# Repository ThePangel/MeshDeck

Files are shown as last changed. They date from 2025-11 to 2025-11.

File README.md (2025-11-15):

# MeshDeck

Standalone ESP32-S3 powered Meshtastic device!

---

Meshdeck is a Standalone Meshtastic device powered by an ESP32-S3, It has a built in keyboard and a touchscreen allowing you to communicate off grid without any phone, completely standalone.

I made this because I wanted to get into Meshtastic, and RF radio stuff, and the best way of learning is making

The keyboard is just a button matrix connected to an RP2040 which will act as an i2c slave and send keycodes to the esp. 

---

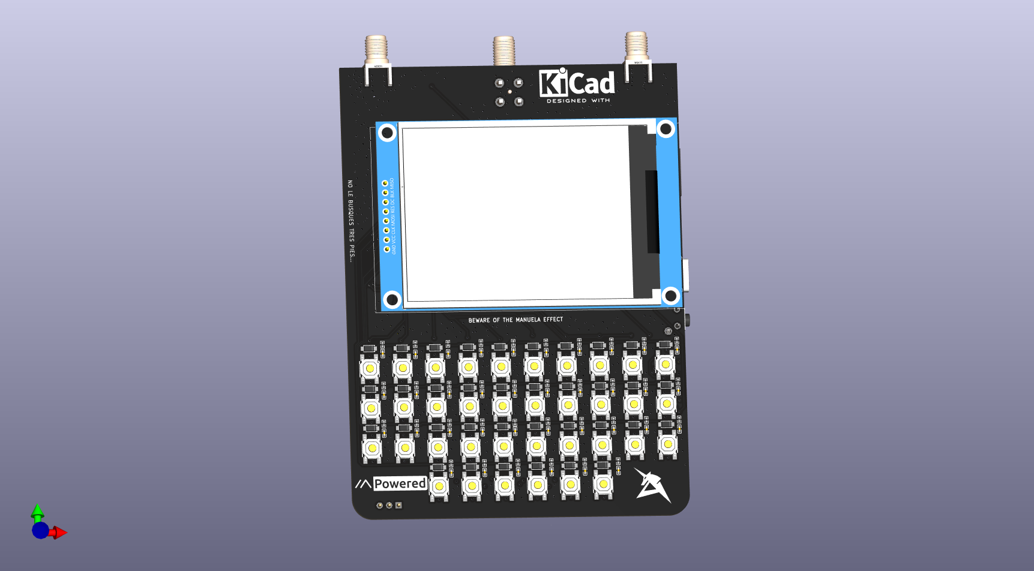
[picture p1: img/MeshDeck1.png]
  
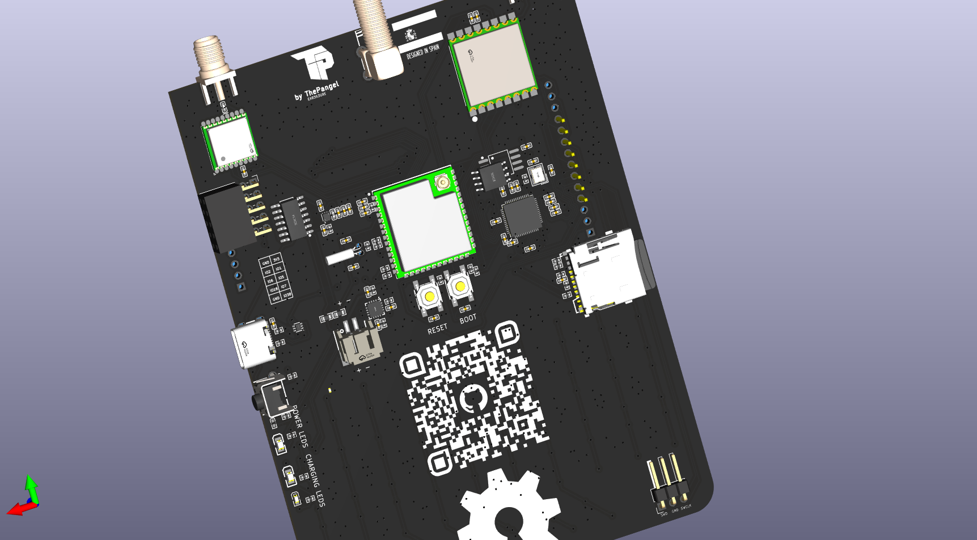
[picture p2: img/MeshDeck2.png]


---

## Bill of Materials (BOM)

| Designator | Footprint | Quantity | Value | LCSC Part # |
|---|---|---|---|---|
| C1 | C0402 | 1 | 22uF | C105226 |
| C10, C11, C12, C19 | C0402 | 4 | 10uF | C15525 |
| C13, C2, C20, C22, C23, C24, C25, C26, C27, C28, C30, C31, C32, C35, C36, C37, C38, C39, C4, C40, C41, C42, C43, C44, C45, C46, C47, C48, C49, C5, C50, C51, C52, C53, C54, C55, C56, C57, C58, C59, C60, C61, C62, C63, C64, C65, C66, C67, C68, C69, C70 | C0402 | 51 | 0.1uF | C1525 |
| C14, C15 | C0402 | 2 | 12pF | C1547 |
| C16, C18, C21, C29, C3, C7 | C0402 | 6 | 1uF | C14445 |
| C17 | C0402 | 1 | 1Nf | C1523 |
| C33, C34 | C0402 | 2 | 15pF | C1548 |
| C6, C8, C9 | C0402 | 3 | 4.7 uF | C23733 |
| CARD1 | TF-SMD_503398-1892 | 1 | 503398-1892 | C428492 |
| CN1 | COMM-SMD_18P-L10.1-W9.7-P1.1-TL_L76-LB  | 1 | ATGM336H-6N-74  | C5804601 |
| D1 | SOT-666-6_L1.6-W1.2-P0.50-LS1.6-BR | 1 | USBLC6-2P6 | C15999 |
| D10-D37 | SOD-123_L2.8-W1.8-LS3.7-RD | 36 | 1N4148W T4 | C2099 |
| H1 | CONN-SMD_2P-P2.00_XUNPU_WAFER-PH2.0-2PWB| 1 | WAFER-PH2.0-2PWB| C3029440 |
| J1 | PinHeader_1x03_P2.54mm_Horizontal | 1 | Conn_01x03_MountingPin | - |
| J2 | PinSocket_2x05_P2.54mm_Horizontal | 1 | Conn_02x05_Odd_Even | - |
| L1 | L0402 | 1 | 0.47 µH | C5788770 |
| L2 | L0402-RD | 1 | 47nH | C471397 |
| LED1, LED3 | LED0805-R-RD | 2 | 0805G (Green) | C2297 |
| LED2 | LED0603-RD | 1 | Blue light 0603 | C2288 |
| LED4 | LED0402-RD | 1 | red | C130719 |
| R1, R13, R17-R25 | R0402 | 9 | 10KOhm | C25531 |
| R10, R9 | R0402 | 2 | 1.8k | C25871 |
| R11, R16 | R0402 | 2 | 10K | C25744 |
| R12, R14, R15, R2-R4 | R0402 | 6 | 0 Ohm | C17168 |
| R19, R20 | R0402 | 2 | 220ohm | C25091 |
| R26-R64 | R0402 | 37 | 1k | C11702 |
| R5, R6 | R0402 | 2 | 5.1k | C25905 |
| R62, R63 | R0603 | 2 | 100k | C14675 |
| R7 | R0402 | 1 | 1.5K | C25867 |
| R8 | R0402 | 1 | 1.5K | C25867 |
| RF1, RF2 | SMA-SMD_HJ-SMA023 | 2 | HJ-SMA023 | C1509219 |
| SW1-SW39 | SW-SMD_4P-L5.2-W5.2-P3.70-LS6.5 | 38 | 4*4*1.7 | C10852 |
| SW3 | KEY-TH_4P-L7.5-W6.8-P4.50-LS7.2 | 1 | SKHHLVA010 | C110289 |
| U1 | WIRELM-SMD_ESP32-S3-WROOM-1U | 1 | ESP32-S3-WROOM-1U-N16R8 | C3013946 |
| U10 | CRYSTAL-SMD_4P-L3.2-W2.5-BL | 1 | ABM8-272-T3_C20625731 | C20625731 |
| U2 | WIRELM-SMD_SX1278S165SY-T-X1 | 1 | SX1262S8S+T-X1  | C718838 |
| U3 | VSON-6_L1.5-W1.5-P0.50-TL | 1 | TPS6282533DMQR  | C3189971 |
| U4 | QFN-16_L3.0-W3.0-P0.50-TL-EP1.7 | 1 | BQ24074RGTR | C54313 |
| U5 | OSC-TH_BD2.0-P0.50 | 1 | RN32768114 | C7206316 |
| U6 | 2.8 SPI LCD TFT ST7789 | 1 | ~ | - |
| U7 | SOIC-14_L8.7-W3.9-P1.27-LS6.0-BL | 1 | CD4013BM | C347580 |
| U8 | LQFN-56_L7.0-W7.0-P0.4-EP | 1 | RP2040 | C2040 |
| U9 | SOIC-8_L5.3-W5.3-P1.27-LS8.0-BL | 1 | W25Q128JVSIQTR  | C97521 |
| USBC1 | USB-C_SMD-TYPE-C-31-M-12_1 | 1 | TYPE-C-31-M-12  | C165948 |

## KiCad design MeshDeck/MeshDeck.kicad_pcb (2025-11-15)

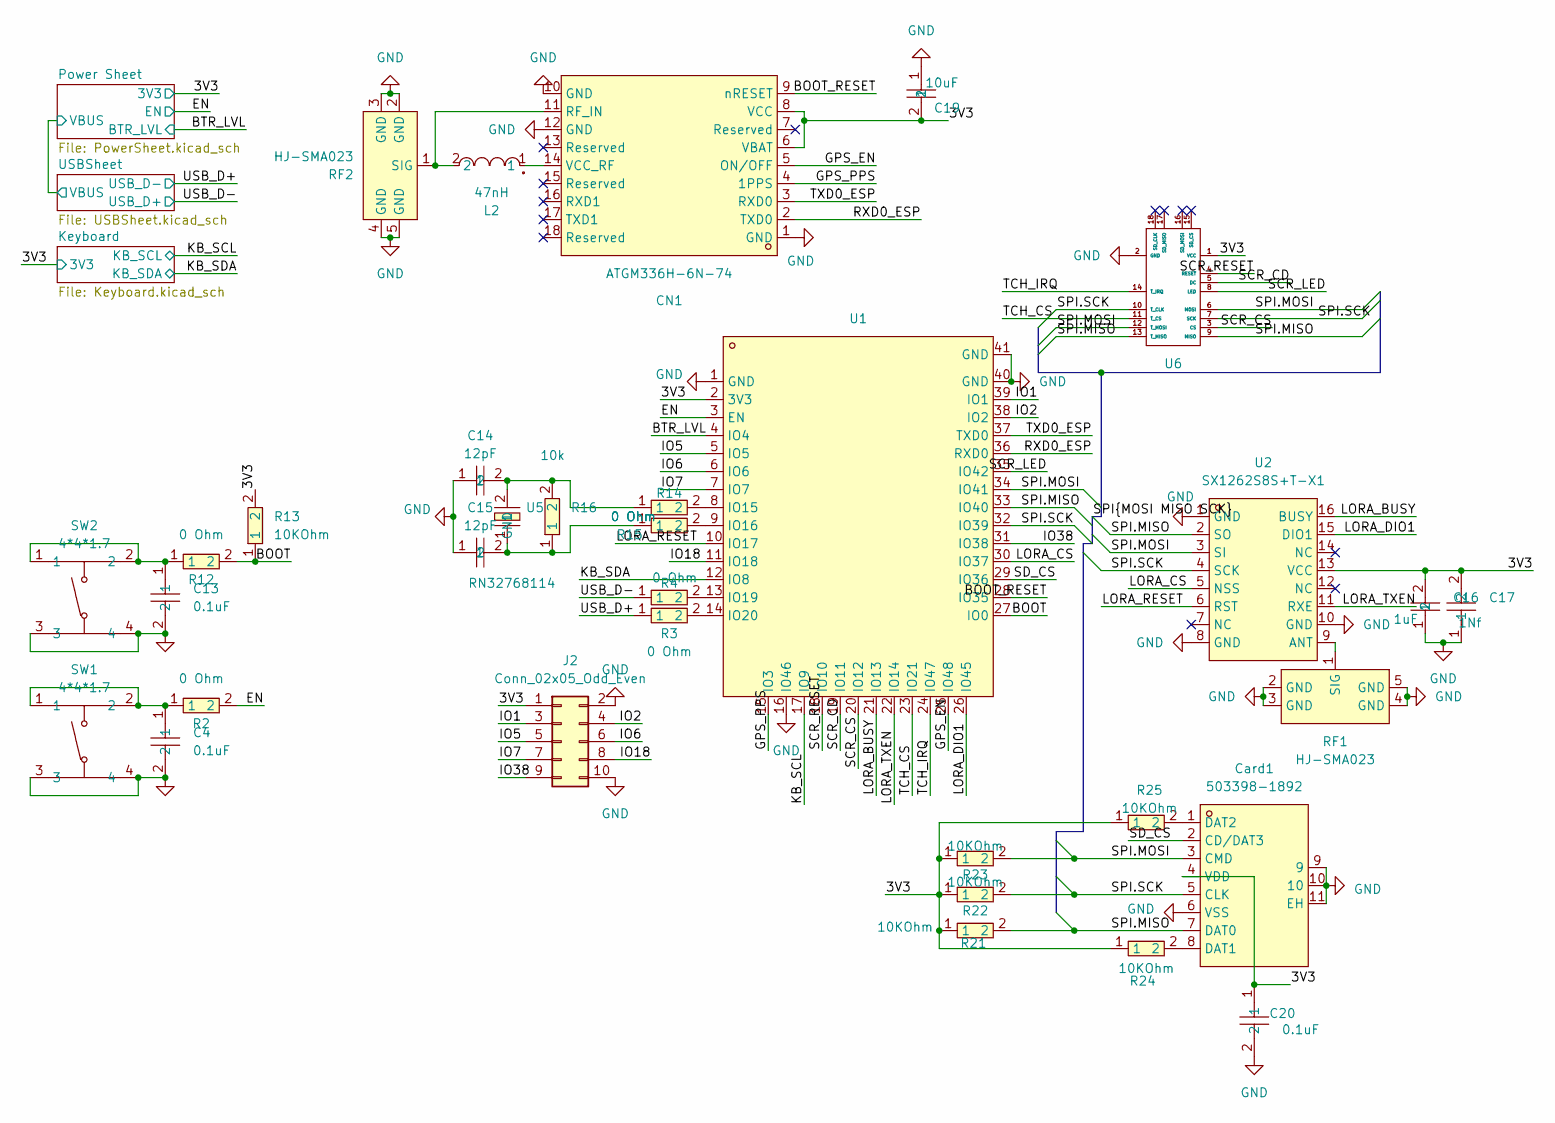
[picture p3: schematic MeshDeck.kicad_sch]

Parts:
C4, C13, C20: 0.1uF; C0402; LCSC Part C1525
C14, C15: 12pF; C0402; LCSC Part C1547
C16: 1uF; C0402; LCSC Part C14445
C17: 1Nf; C0402; LCSC Part C1523
C19: 10uF; C0402; LCSC Part C15525
CN1: ATGM336H-6N-74; COMM-SMD_18P-L10.1-W9.7-P1.1-TL_L76-LB; LCSC Part C5804601
Card1: 503398-1892; TF-SMD_503398-1892; LCSC Part C428492
J2: Conn_02x05_Odd_Even; PinSocket_2x05_P2.54mm_Horizontal
L2: 47nH; L0402-RD; LCSC Part C471397
R2, R3, R4, R12, R14, R15: 0 Ohm; R0402; LCSC Part C17168
R13, R21, R22, R23, R24, R25: 10KOhm; R0402; LCSC Part C25531
R16: 10k; R0402; LCSC Part C25744
RF1, RF2: HJ-SMA023; SMA-SMD_HJ-SMA023; LCSC Part C1509219
SW1, SW2: 4*4*1.7; SW-SMD_4P-L5.2-W5.2-P3.70-LS6.5; LCSC Part C10852
U1: ESP32-S3-WROOM-1U-N16R8; WIRELM-SMD_ESP32-S3-WROOM-1U; LCSC Part C3013946
U2: SX1262S8S+T-X1; WIRELM-SMD_SX1278S165SY-T-X1; LCSC Part C718838
U5: RN32768114; OSC-TH_BD2.0-P0.50; LCSC Part C7206316
U6: 2.8 SPI LCD TFT ST7789

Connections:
/3V3: C16.2, C17.2, C19.2, C20.1, CN1.6 (VBAT), CN1.8 (VCC), Card1.4 (VDD), J2.1, R13.2, R21.1, R22.1, R23.1, R24.1, R25.1, U1.2 (3V3), U2.13 (VCC), U6.1 (VCC); also elsewhere on the board
/BOOT: R12.2, R13.1, U1.27 (IO0)
/BOOT_RESET: CN1.9 (nRESET), U1.28 (IO35)
/BTR_LVL: U1.4 (IO4); also elsewhere on the board
/EN: R2.2, U1.3 (EN); also elsewhere on the board
/GPS_EN: CN1.5 (ON/OFF), U1.25 (IO48)
/GPS_PPS: CN1.4 (1PPS), U1.15 (IO3)
/IO1: J2.3, U1.39 (IO1)
/IO2: J2.4, U1.38 (IO2)
/IO5: J2.5, U1.5 (IO5)
/IO6: J2.6, U1.6 (IO6)
/IO7: J2.7, U1.7 (IO7)
/IO18: J2.8, U1.11 (IO18)
/IO38: J2.9, U1.31 (IO38)
/KB_SCL: U1.17 (IO9); also elsewhere on the board
/KB_SDA: U1.12 (IO8); also elsewhere on the board
/LORA_BUSY: U1.21 (IO13), U2.16 (BUSY)
/LORA_CS: U1.30 (IO37), U2.5 (NSS)
/LORA_DIO1: U1.26 (IO45), U2.15 (DIO1)
/LORA_RESET: U1.10 (IO17), U2.6 (RST)
/LORA_TXEN: U1.22 (IO14), U2.11 (RXE)
/RXD0_ESP: CN1.2 (TXD0), U1.36 (RXD0)
/SCR_CD: U1.19 (IO11), U6.5 (DC)
/SCR_CS: U1.20 (IO12), U6.3 (CS)
/SCR_LED: U1.35 (IO42), U6.8 (LED)
/SCR_RESET: U1.18 (IO10), U6.4 (RESET)
/SD_CS: Card1.2 (CD/DAT3), U1.29 (IO36)
/SPI.MISO: Card1.7 (DAT0), R21.2, U1.33 (IO40), U2.2 (SO), U6.9 (MISO), U6.13 (T_MISO)
/SPI.MOSI: Card1.3 (CMD), R23.2, U1.34 (IO41), U2.3 (SI), U6.6 (MOSI), U6.12 (T_MOSI)
/SPI.SCK: Card1.5 (CLK), R22.2, U1.32 (IO39), U2.4 (SCK), U6.7 (SCK), U6.10 (T_CLK)
/TCH_CS: U1.23 (IO21), U6.11 (T_CS)
/TCH_IRQ: U1.24 (IO47), U6.14 (T_IRQ)
/TXD0_ESP: CN1.3 (RXD0), U1.37 (TXD0)
/USB_D+: R3.1; also elsewhere on the board
/USB_D-: R4.1; also elsewhere on the board
GND: C4.2, C13.2, C14.1, C15.1, C16.1, C17.1, C19.1, C20.2, CN1.1 (GND), CN1.10 (GND), CN1.12 (GND), Card1.6 (VSS), Card1.9, Card1.10, Card1.11 (EH), J2.2, J2.10, RF1.2 (GND), RF1.3 (GND), RF1.4 (GND), RF1.5 (GND), RF2.2 (GND), RF2.3 (GND), RF2.4 (GND), RF2.5 (GND), SW1.3, SW1.4, SW2.3, SW2.4, U1.1 (GND), U1.16 (IO46), U1.40 (GND), U1.41 (GND), U2.1 (GND), U2.8 (GND), U2.10 (GND), U6.2 (GND); also elsewhere on the board
unnamed: C4.1, R2.1, SW1.1, SW1.2
unnamed: C13.1, R12.1, SW2.1, SW2.2
unnamed: C15.2, R15.1, R16.1, U5.1
unnamed: CN1.11 (RF_IN), L2.2, RF2.1 (SIG)
unnamed: CN1.14 (VCC_RF), L2.1
unnamed: Card1.8 (DAT1), R24.2
unnamed: Card1.1 (DAT2), R25.2
unnamed: RF1.1 (SIG), U2.9 (ANT)
unnamed: R14.2, U1.8 (IO15)
unnamed: R15.2, U1.9 (IO16)
unnamed: R4.2, U1.13 (IO19)
unnamed: R3.2, U1.14 (IO20)
unnamed: C14.2, R14.1, R16.2, U5.2 (GND)

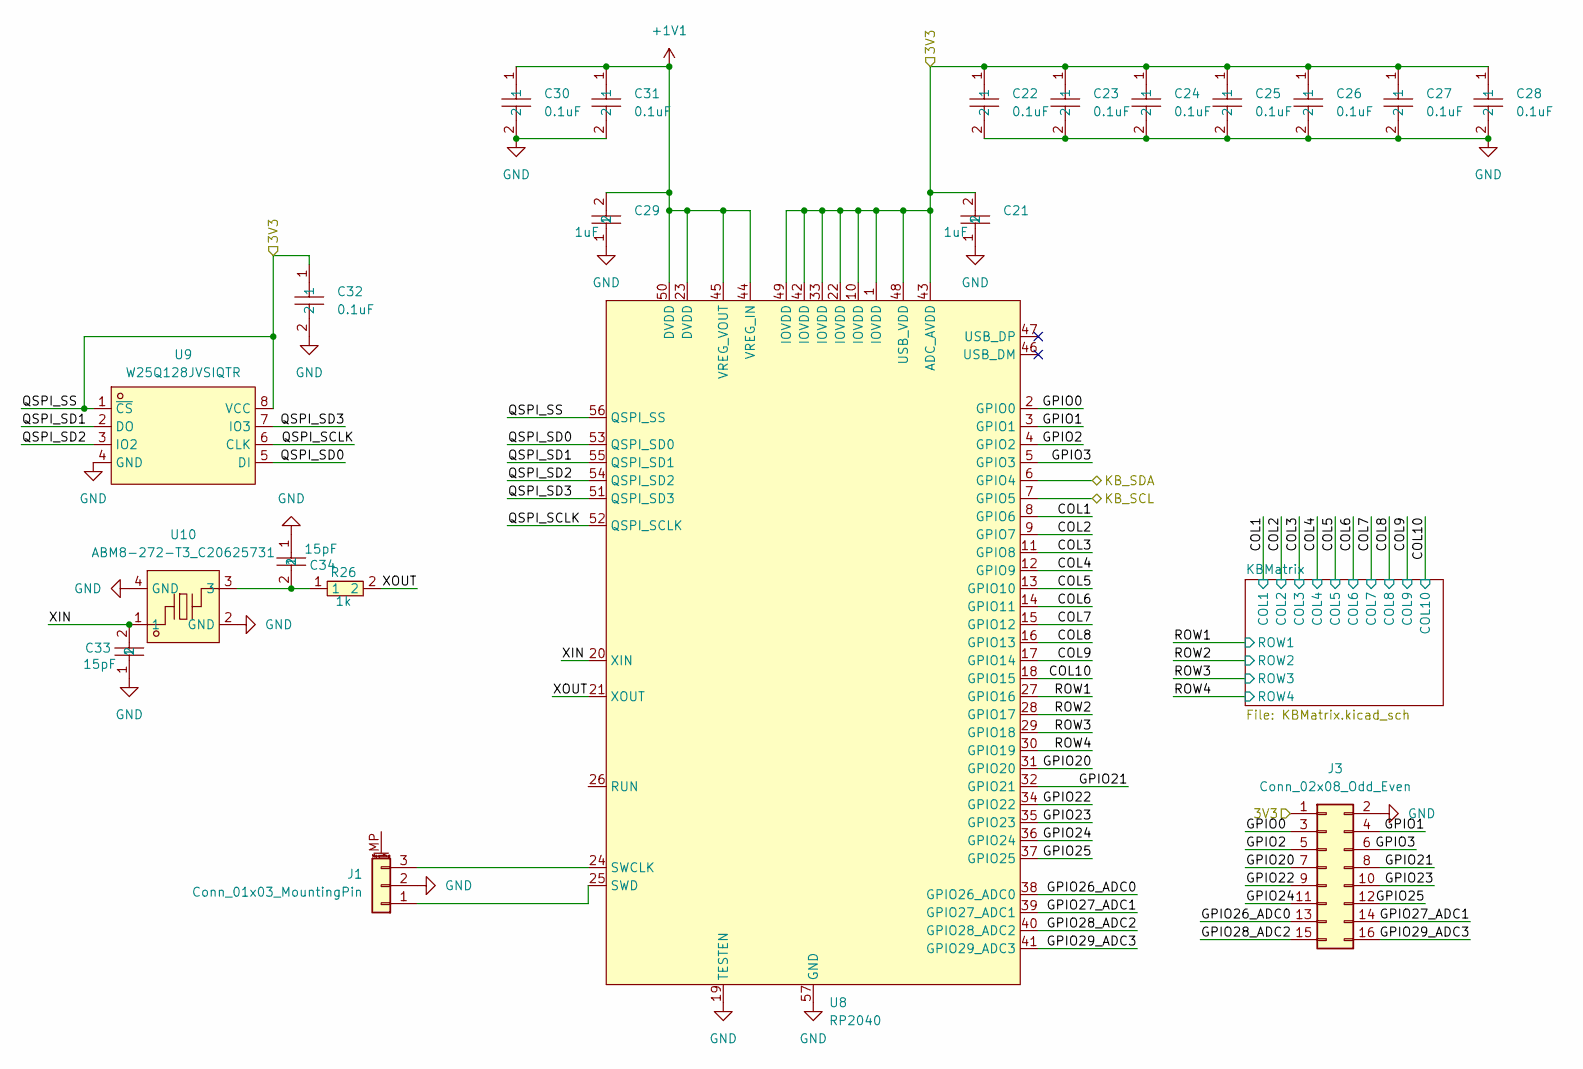
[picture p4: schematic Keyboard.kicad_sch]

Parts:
C21, C29: 1uF; C0402; LCSC Part C14445
C22, C23, C24, C25, C26, C27, C28, C30, C31, C32: 0.1uF; C0402; LCSC Part C1525
C33, C34: 15pF; C0402; LCSC Part C1548
J1: Conn_01x03_MountingPin; PinHeader_1x03_P2.54mm_Horizontal
J3: Conn_02x08_Odd_Even; PinSocket_2x08_P2.54mm_Horizontal
R26: 1k; R0402; LCSC Part C11702
U8: RP2040; LQFN-56_L7.0-W7.0-P0.4-EP; LCSC Part C2040
U9: W25Q128JVSIQTR; SOIC-8_L5.3-W5.3-P1.27-LS8.0-BL; LCSC Part C97521
U10: ABM8-272-T3_C20625731; CRYSTAL-SMD_4P-L3.2-W2.5-BL; LCSC Part C20625731

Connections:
+1V1: C29.2, C30.1, C31.1, U8.23 (DVDD), U8.44 (VREG_IN), U8.45 (VREG_VOUT), U8.50 (DVDD)
/3V3: C21.2, C22.1, C23.1, C24.1, C25.1, C26.1, C27.1, C28.1, C32.1, J3.1, U8.1 (IOVDD), U8.10 (IOVDD), U8.22 (IOVDD), U8.33 (IOVDD), U8.42 (IOVDD), U8.43 (ADC_AVDD), U8.48 (USB_VDD), U8.49 (IOVDD), U8.56 (QSPI_SS), U9.1 (~CS), U9.8 (VCC); also elsewhere on the board
/KB_SCL: U8.7 (GPIO5); also elsewhere on the board
/KB_SDA: U8.6 (GPIO4); also elsewhere on the board
/Keyboard/COL1: U8.8 (GPIO6); also elsewhere on the board
/Keyboard/COL2: U8.9 (GPIO7); also elsewhere on the board
/Keyboard/COL3: U8.11 (GPIO8); also elsewhere on the board
/Keyboard/COL4: U8.12 (GPIO9); also elsewhere on the board
/Keyboard/COL5: U8.13 (GPIO10); also elsewhere on the board
/Keyboard/COL6: U8.14 (GPIO11); also elsewhere on the board
/Keyboard/COL7: U8.15 (GPIO12); also elsewhere on the board
/Keyboard/COL8: U8.16 (GPIO13); also elsewhere on the board
/Keyboard/COL9: U8.17 (GPIO14); also elsewhere on the board
/Keyboard/COL10: U8.18 (GPIO15); also elsewhere on the board
/Keyboard/GPIO0: J3.3, U8.2 (GPIO0)
/Keyboard/GPIO1: J3.4, U8.3 (GPIO1)
/Keyboard/GPIO2: J3.5, U8.4 (GPIO2)
/Keyboard/GPIO3: J3.6, U8.5 (GPIO3)
/Keyboard/GPIO20: J3.7, U8.31 (GPIO20)
/Keyboard/GPIO21: J3.8, U8.32 (GPIO21)
/Keyboard/GPIO22: J3.9, U8.34 (GPIO22)
/Keyboard/GPIO23: J3.10, U8.35 (GPIO23)
/Keyboard/GPIO24: J3.11, U8.36 (GPIO24)
/Keyboard/GPIO25: J3.12, U8.37 (GPIO25)
/Keyboard/GPIO26_ADC0: J3.13, U8.38 (GPIO26_ADC0)
/Keyboard/GPIO27_ADC1: J3.14, U8.39 (GPIO27_ADC1)
/Keyboard/GPIO28_ADC2: J3.15, U8.40 (GPIO28_ADC2)
/Keyboard/GPIO29_ADC3: J3.16, U8.41 (GPIO29_ADC3)
/Keyboard/QSPI_SCLK: U8.52 (QSPI_SCLK), U9.6 (CLK)
/Keyboard/QSPI_SD0: U8.53 (QSPI_SD0), U9.5 (DI)
/Keyboard/QSPI_SD1: U8.55 (QSPI_SD1), U9.2 (DO)
/Keyboard/QSPI_SD2: U8.54 (QSPI_SD2), U9.3 (IO2)
/Keyboard/QSPI_SD3: U8.51 (QSPI_SD3), U9.7 (IO3)
/Keyboard/ROW1: U8.27 (GPIO16); also elsewhere on the board
/Keyboard/ROW2: U8.28 (GPIO17); also elsewhere on the board
/Keyboard/ROW3: U8.29 (GPIO18); also elsewhere on the board
/Keyboard/ROW4: U8.30 (GPIO19); also elsewhere on the board
/Keyboard/XIN: C33.2, U8.20 (XIN), U10.1
/Keyboard/XOUT: R26.2, U8.21 (XOUT)
GND: C21.1, C22.2, C23.2, C24.2, C25.2, C26.2, C27.2, C28.2, C29.1, C30.2, C31.2, C32.2, C33.1, C34.1, J1.2, J3.2, U8.19 (TESTEN), U8.57 (GND), U9.4 (GND), U10.2 (GND), U10.4 (GND); also elsewhere on the board
unnamed: C34.2, R26.1, U10.3
unnamed: J1.1, U8.25 (SWD)
unnamed: J1.3, U8.24 (SWCLK)

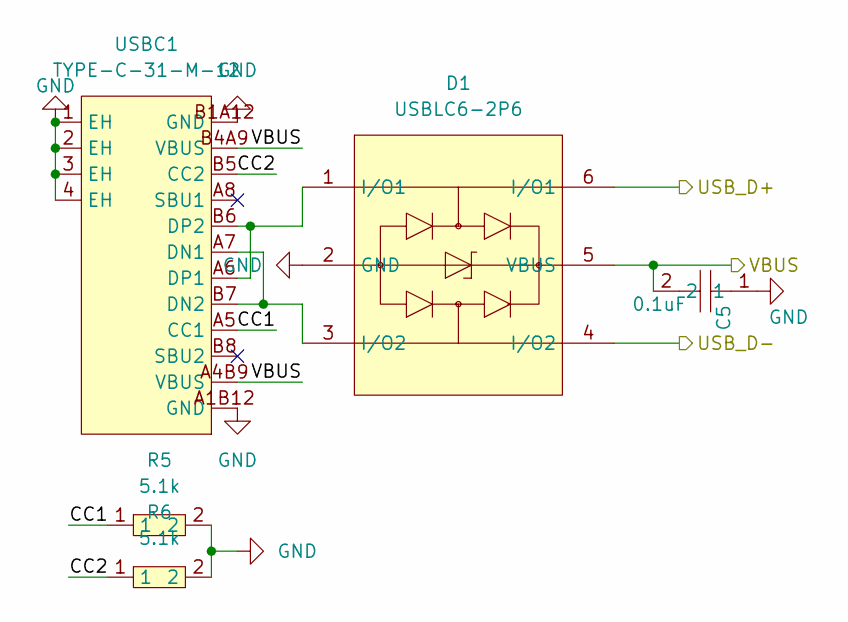
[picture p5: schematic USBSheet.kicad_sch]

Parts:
C5: 0.1uF; C0402; LCSC Part C1525
D1: USBLC6-2P6; SOT-666-6_L1.6-W1.2-P0.50-LS1.6-BR; LCSC Part C15999
R5, R6: 5.1k; R0402; LCSC Part C25905
USBC1: TYPE-C-31-M-12; USB-C_SMD-TYPE-C-31-M-12_1; LCSC Part C165948

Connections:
/USBSheet/CC1: R5.1, USBC1.A5 (CC1)
/USBSheet/CC2: R6.1, USBC1.B5 (CC2)
/USBSheet/VBUS: C5.2, D1.5 (VBUS), USBC1.A4B9 (VBUS), USBC1.B4A9 (VBUS); also elsewhere on the board
/USB_D+: D1.4 (I/O2); also elsewhere on the board
/USB_D-: D1.6 (I/O1); also elsewhere on the board
GND: C5.1, D1.2 (GND), R5.2, R6.2, USBC1.1 (EH), USBC1.2 (EH), USBC1.3 (EH), USBC1.4 (EH), USBC1.A1B12 (GND), USBC1.B1A12 (GND); also elsewhere on the board
unnamed: D1.3 (I/O2), USBC1.A7 (DN1), USBC1.B7 (DN2)
unnamed: D1.1 (I/O1), USBC1.A6 (DP1), USBC1.B6 (DP2)

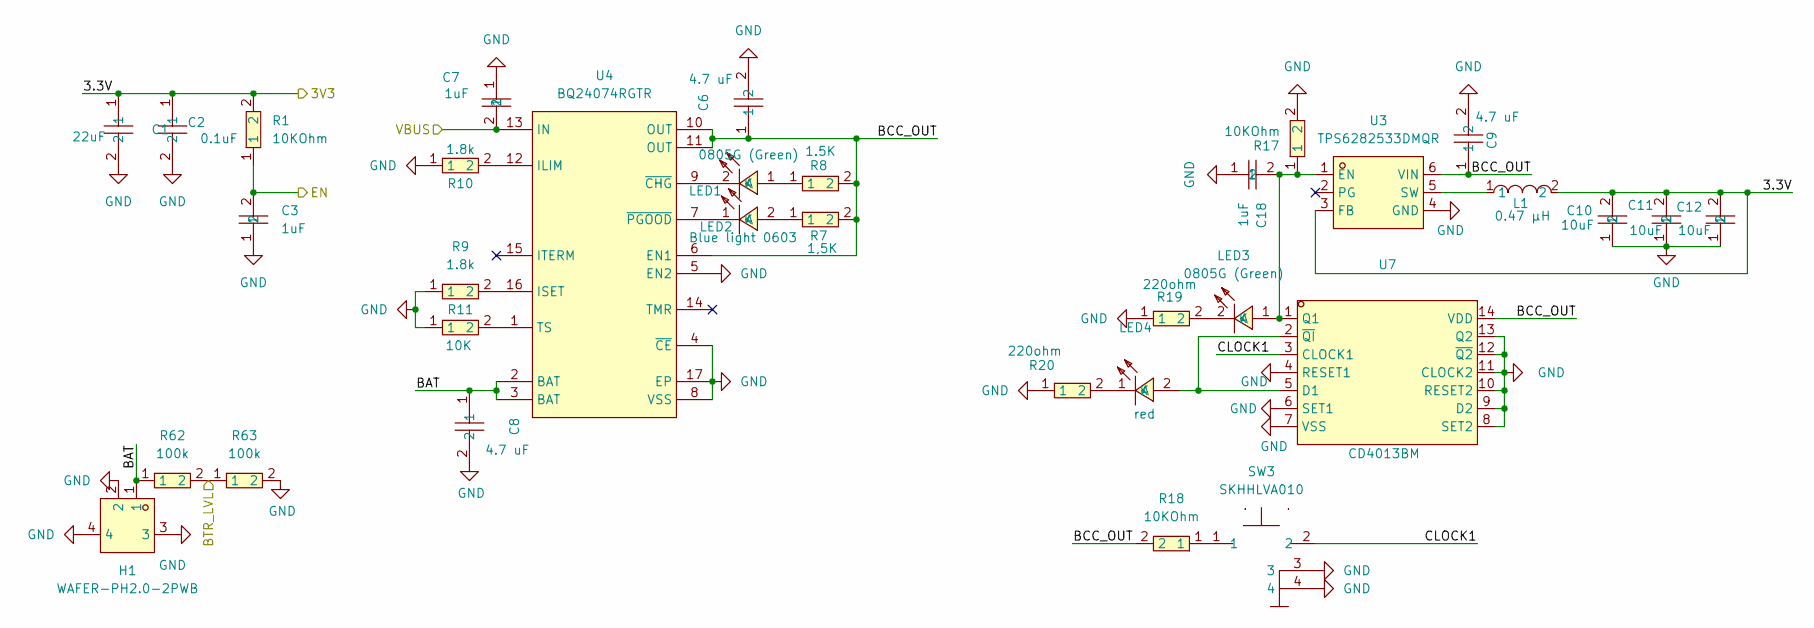
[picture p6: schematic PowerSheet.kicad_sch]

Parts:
C1: 22uF; C0402; LCSC Part C105226
C2: 0.1uF; C0402; LCSC Part C1525
C3, C7, C18: 1uF; C0402; LCSC Part C14445
C6, C8, C9: 4.7 uF; C0402; LCSC Part C23733
C10, C11, C12: 10uF; C0402; LCSC Part C15525
H1: WAFER-PH2.0-2PWB; CONN-SMD_2P-P2.00_XUNPU_WAFER-PH2.0-2PWB; LCSC Part C3029440
L1: 0.47 µH; L0402; LCSC Part C5788770
LED1, LED3: 0805G (Green); LED0805-R-RD; LCSC Part C2297
LED2: Blue light 0603; LED0603-RD; LCSC Part C2288
LED4: red; LED0402-RD; LCSC Part C130719
R1, R17, R18: 10KOhm; R0402; LCSC Part C25531
R7: 1,5K; R0402; LCSC Part C25867
R8: 1.5K; R0402; LCSC Part C25867
R9, R10: 1.8k; R0402; LCSC Part C25871
R11: 10K; R0402; LCSC Part C25744
R19, R20: 220ohm; R0402; LCSC Part C25091
R62, R63: 100k; R0603; LCSC Part C14675
SW3: SKHHLVA010; KEY-TH_4P-L7.5-W6.8-P4.50-LS7.2; LCSC Part C110289
U3: TPS6282533DMQR; VSON-6_L1.5-W1.5-P0.50-TL; LCSC Part C3189971
U4: BQ24074RGTR; QFN-16_L3.0-W3.0-P0.50-TL-EP1.7; LCSC Part C54313
U7: CD4013BM; SOIC-14_L8.7-W3.9-P1.27-LS6.0-BL; LCSC Part C347580

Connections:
/3V3: C1.1, C2.1, C10.2, C11.2, C12.2, L1.2, R1.2, U3.3 (FB); also elsewhere on the board
/BTR_LVL: R62.2, R63.1; also elsewhere on the board
/EN: C3.2, R1.1; also elsewhere on the board
/Power Sheet/BAT: C8.1, H1.1, R62.1, U4.2 (BAT), U4.3 (BAT)
/Power Sheet/BCC_OUT: C6.1, C9.1, R7.2, R8.2, R18.2, U3.6 (VIN), U4.6 (EN1), U4.10 (OUT), U4.11 (OUT), U7.14 (VDD)
/Power Sheet/CLOCK1: SW3.2, U7.3 (CLOCK1)
/USBSheet/VBUS: C7.2, U4.13 (IN); also elsewhere on the board
GND: C1.2, C2.2, C3.1, C6.2, C7.1, C8.2, C9.2, C10.1, C11.1, C12.1, C18.1, H1.2, H1.3, H1.4, R9.1, R10.1, R11.1, R17.2, R19.1, R20.1, R63.2, SW3.3, SW3.4, U3.4 (GND), U4.4 (~CE), U4.5 (EN2), U4.8 (VSS), U4.17 (EP), U7.4 (RESET1), U7.6 (SET1), U7.7 (VSS), U7.8 (SET2), U7.9 (D2), U7.10 (RESET2), U7.11 (CLOCK2), U7.12 (~Q2), U7.13 (Q2); also elsewhere on the board
unnamed: LED1.1 (A), R8.1
unnamed: LED1.2 (K), U4.9 (~CHG)
unnamed: LED2.2 (A), R7.1
unnamed: LED2.1 (K), U4.7 (~PGOOD)
unnamed: C18.2, LED3.1 (A), R17.1, U3.1 (EN), U7.1 (Q1)
unnamed: LED3.2 (K), R19.2
unnamed: LED4.2 (A), U7.2 (~QI), U7.5 (D1)
unnamed: LED4.1 (K), R20.2
unnamed: R18.1, SW3.1
unnamed: L1.1, U3.5 (SW)
unnamed: R10.2, U4.12 (ILIM)
unnamed: R9.2, U4.16 (ISET)
unnamed: R11.2, U4.1 (TS)

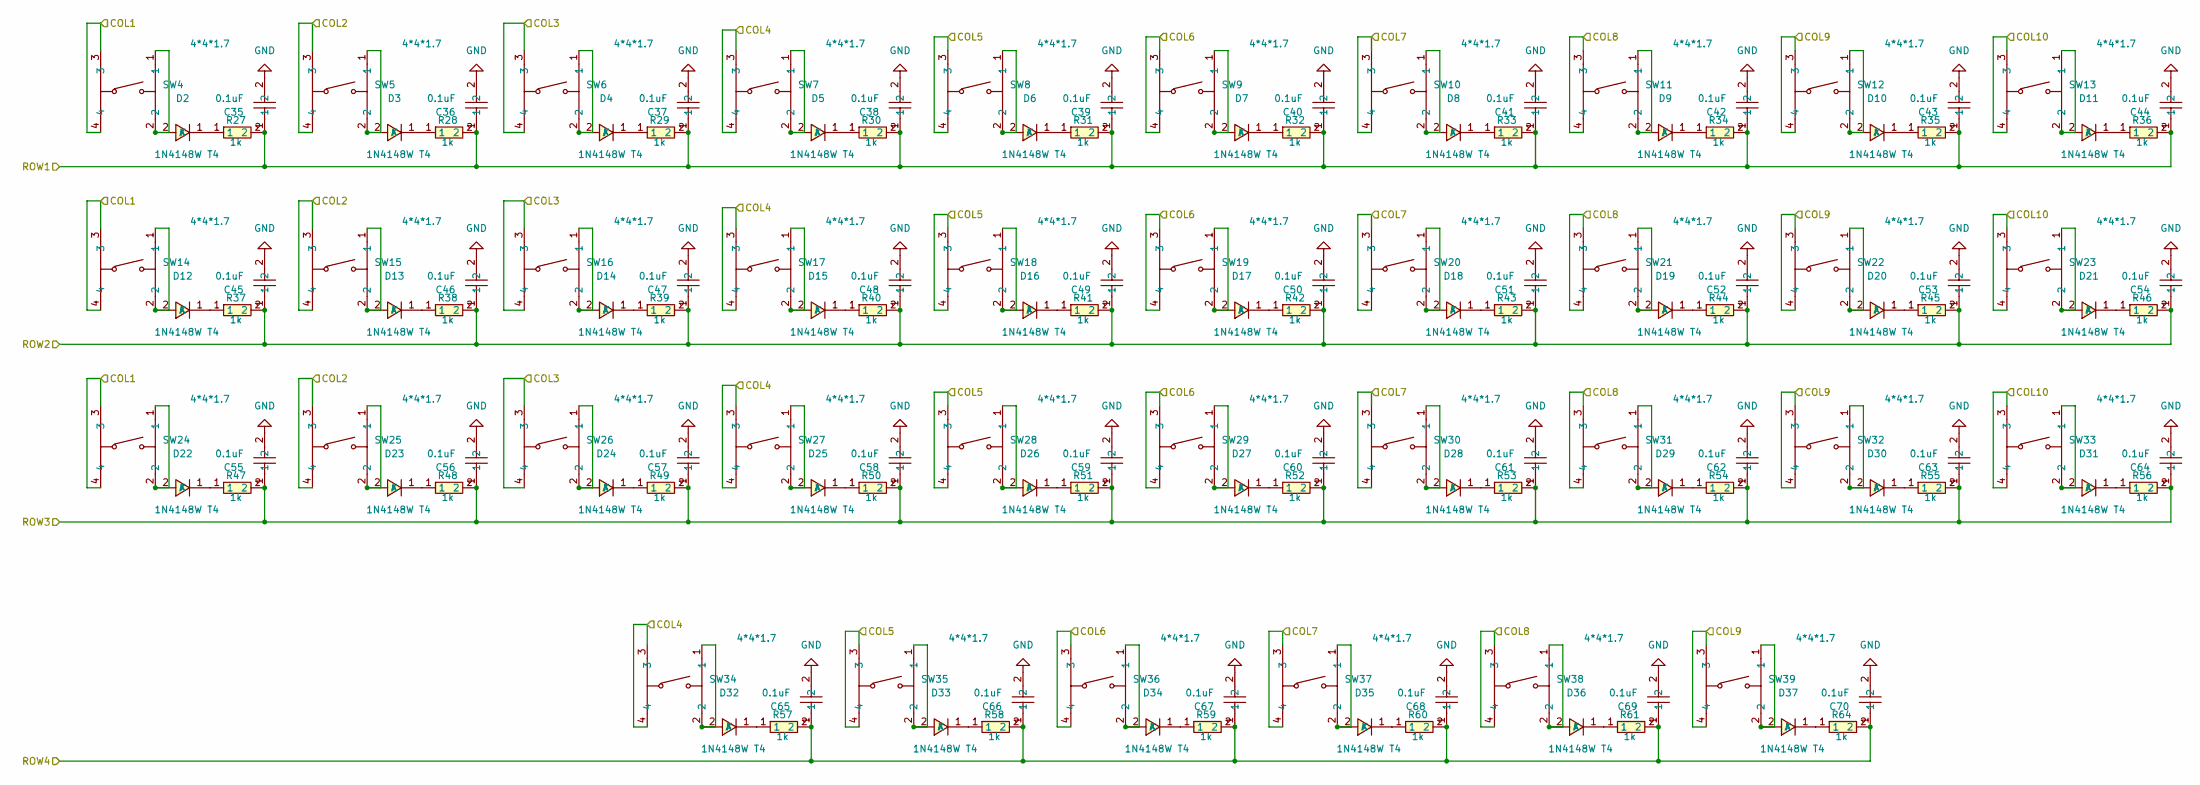
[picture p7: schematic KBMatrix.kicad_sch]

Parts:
C35, C36, C37, C38, C39, C40, C41, C42, C43, C44, C45, C46, C47, C48, C49, C50, C51, C52, C53, C54, C55, C56, C57, C58, C59, C60, C61, C62, C63, C64, C65, C66, C67, C68, C69, C70: 0.1uF; C0402; LCSC Part C1525
D2, D3, D4, D5, D6, D7, D8, D9, D10, D11, D12, D13, D14, D15, D16, D17, D18, D19, D20, D21, D22, D23, D24, D25, D26, D27, D28, D29, D30, D31, D32, D33, D34, D35, D36, D37: 1N4148W T4; SOD-123_L2.8-W1.8-LS3.7-RD; LCSC Part C2099
R27, R28, R29, R30, R31, R32, R33, R34, R35, R36, R37, R38, R39, R40, R41, R42, R43, R44, R45, R46, R47, R48, R49, R50, R51, R52, R53, R54, R55, R56, R57, R58, R59, R60, R61, R64: 1k; R0402; LCSC Part C11702
SW4, SW5, SW6, SW7, SW8, SW9, SW10, SW11, SW12, SW13, SW14, SW15, SW16, SW17, SW18, SW19, SW20, SW21, SW22, SW23, SW24, SW25, SW26, SW27, SW28, SW29, SW30, SW31, SW32, SW33, SW34, SW35, SW36, SW37, SW38, SW39: 4*4*1.7; SW-SMD_4P-L5.2-W5.2-P3.70-LS6.5; LCSC Part C10852

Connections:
/Keyboard/COL1: SW4.3, SW4.4, SW14.3, SW14.4, SW24.3, SW24.4; also elsewhere on the board
/Keyboard/COL2: SW5.3, SW5.4, SW15.3, SW15.4, SW25.3, SW25.4; also elsewhere on the board
/Keyboard/COL3: SW6.3, SW6.4, SW16.3, SW16.4, SW26.3, SW26.4; also elsewhere on the board
/Keyboard/COL4: SW7.3, SW7.4, SW17.3, SW17.4, SW27.3, SW27.4, SW34.3, SW34.4; also elsewhere on the board
/Keyboard/COL5: SW8.3, SW8.4, SW18.3, SW18.4, SW28.3, SW28.4, SW35.3, SW35.4; also elsewhere on the board
/Keyboard/COL6: SW9.3, SW9.4, SW19.3, SW19.4, SW29.3, SW29.4, SW36.3, SW36.4; also elsewhere on the board
/Keyboard/COL7: SW10.3, SW10.4, SW20.3, SW20.4, SW30.3, SW30.4, SW37.3, SW37.4; also elsewhere on the board
/Keyboard/COL8: SW11.3, SW11.4, SW21.3, SW21.4, SW31.3, SW31.4, SW38.3, SW38.4; also elsewhere on the board
/Keyboard/COL9: SW12.3, SW12.4, SW22.3, SW22.4, SW32.3, SW32.4, SW39.3, SW39.4; also elsewhere on the board
/Keyboard/COL10: SW13.3, SW13.4, SW23.3, SW23.4, SW33.3, SW33.4; also elsewhere on the board
/Keyboard/ROW1: C35.1, C36.1, C37.1, C38.1, C39.1, C40.1, C41.1, C42.1, C43.1, C44.1, R27.2, R28.2, R29.2, R30.2, R31.2, R32.2, R33.2, R34.2, R35.2, R36.2; also elsewhere on the board
/Keyboard/ROW2: C45.1, C46.1, C47.1, C48.1, C49.1, C50.1, C51.1, C52.1, C53.1, C54.1, R37.2, R38.2, R39.2, R40.2, R41.2, R42.2, R43.2, R44.2, R45.2, R46.2; also elsewhere on the board
/Keyboard/ROW3: C55.1, C56.1, C57.1, C58.1, C59.1, C60.1, C61.1, C62.1, C63.1, C64.1, R47.2, R48.2, R49.2, R50.2, R51.2, R52.2, R53.2, R54.2, R55.2, R56.2; also elsewhere on the board
/Keyboard/ROW4: C65.1, C66.1, C67.1, C68.1, C69.1, C70.1, R57.2, R58.2, R59.2, R60.2, R61.2, R64.2; also elsewhere on the board
GND: C35.2, C36.2, C37.2, C38.2, C39.2, C40.2, C41.2, C42.2, C43.2, C44.2, C45.2, C46.2, C47.2, C48.2, C49.2, C50.2, C51.2, C52.2, C53.2, C54.2, C55.2, C56.2, C57.2, C58.2, C59.2, C60.2, C61.2, C62.2, C63.2, C64.2, C65.2, C66.2, C67.2, C68.2, C69.2, C70.2; also elsewhere on the board
unnamed: D2.2 (A), SW4.1, SW4.2
unnamed: D2.1 (K), R27.1
unnamed: D3.2 (A), SW5.1, SW5.2
unnamed: D3.1 (K), R28.1
unnamed: D4.2 (A), SW6.1, SW6.2
unnamed: D4.1 (K), R29.1
unnamed: D5.2 (A), SW7.1, SW7.2
unnamed: D5.1 (K), R30.1
unnamed: D6.2 (A), SW8.1, SW8.2
unnamed: D6.1 (K), R31.1
unnamed: D7.2 (A), SW9.1, SW9.2
unnamed: D7.1 (K), R32.1
unnamed: D8.2 (A), SW10.1, SW10.2
unnamed: D8.1 (K), R33.1
unnamed: D9.2 (A), SW11.1, SW11.2
unnamed: D9.1 (K), R34.1
unnamed: D10.2 (A), SW12.1, SW12.2
unnamed: D10.1 (K), R35.1
unnamed: D11.2 (A), SW13.1, SW13.2
unnamed: D11.1 (K), R36.1
unnamed: D12.2 (A), SW14.1, SW14.2
unnamed: D12.1 (K), R37.1
unnamed: D13.2 (A), SW15.1, SW15.2
unnamed: D13.1 (K), R38.1
unnamed: D14.2 (A), SW16.1, SW16.2
unnamed: D14.1 (K), R39.1
unnamed: D15.2 (A), SW17.1, SW17.2
unnamed: D15.1 (K), R40.1
unnamed: D16.2 (A), SW18.1, SW18.2
unnamed: D16.1 (K), R41.1
unnamed: D17.2 (A), SW19.1, SW19.2
unnamed: D17.1 (K), R42.1
unnamed: D18.2 (A), SW20.1, SW20.2
unnamed: D18.1 (K), R43.1
unnamed: D19.2 (A), SW21.1, SW21.2
unnamed: D19.1 (K), R44.1
unnamed: D20.2 (A), SW22.1, SW22.2
unnamed: D20.1 (K), R45.1
unnamed: D21.2 (A), SW23.1, SW23.2
unnamed: D21.1 (K), R46.1
unnamed: D22.2 (A), SW24.1, SW24.2
unnamed: D22.1 (K), R47.1
unnamed: D23.2 (A), SW25.1, SW25.2
unnamed: D23.1 (K), R48.1
unnamed: D24.2 (A), SW26.1, SW26.2
unnamed: D24.1 (K), R49.1
unnamed: D25.2 (A), SW27.1, SW27.2
unnamed: D25.1 (K), R50.1
unnamed: D26.2 (A), SW28.1, SW28.2
unnamed: D26.1 (K), R51.1
unnamed: D27.2 (A), SW29.1, SW29.2
unnamed: D27.1 (K), R52.1
unnamed: D28.2 (A), SW30.1, SW30.2
unnamed: D28.1 (K), R53.1
unnamed: D29.2 (A), SW31.1, SW31.2
unnamed: D29.1 (K), R54.1
unnamed: D30.2 (A), SW32.1, SW32.2
unnamed: D30.1 (K), R55.1
unnamed: D31.2 (A), SW33.1, SW33.2
unnamed: D31.1 (K), R56.1
unnamed: D32.2 (A), SW34.1, SW34.2
unnamed: D32.1 (K), R57.1
unnamed: D33.2 (A), SW35.1, SW35.2
unnamed: D33.1 (K), R58.1
unnamed: D34.2 (A), SW36.1, SW36.2
unnamed: D34.1 (K), R59.1
unnamed: D35.2 (A), SW37.1, SW37.2
unnamed: D35.1 (K), R60.1
unnamed: D36.2 (A), SW38.1, SW38.2
unnamed: D36.1 (K), R61.1
unnamed: D37.2 (A), SW39.1, SW39.2
unnamed: D37.1 (K), R64.1

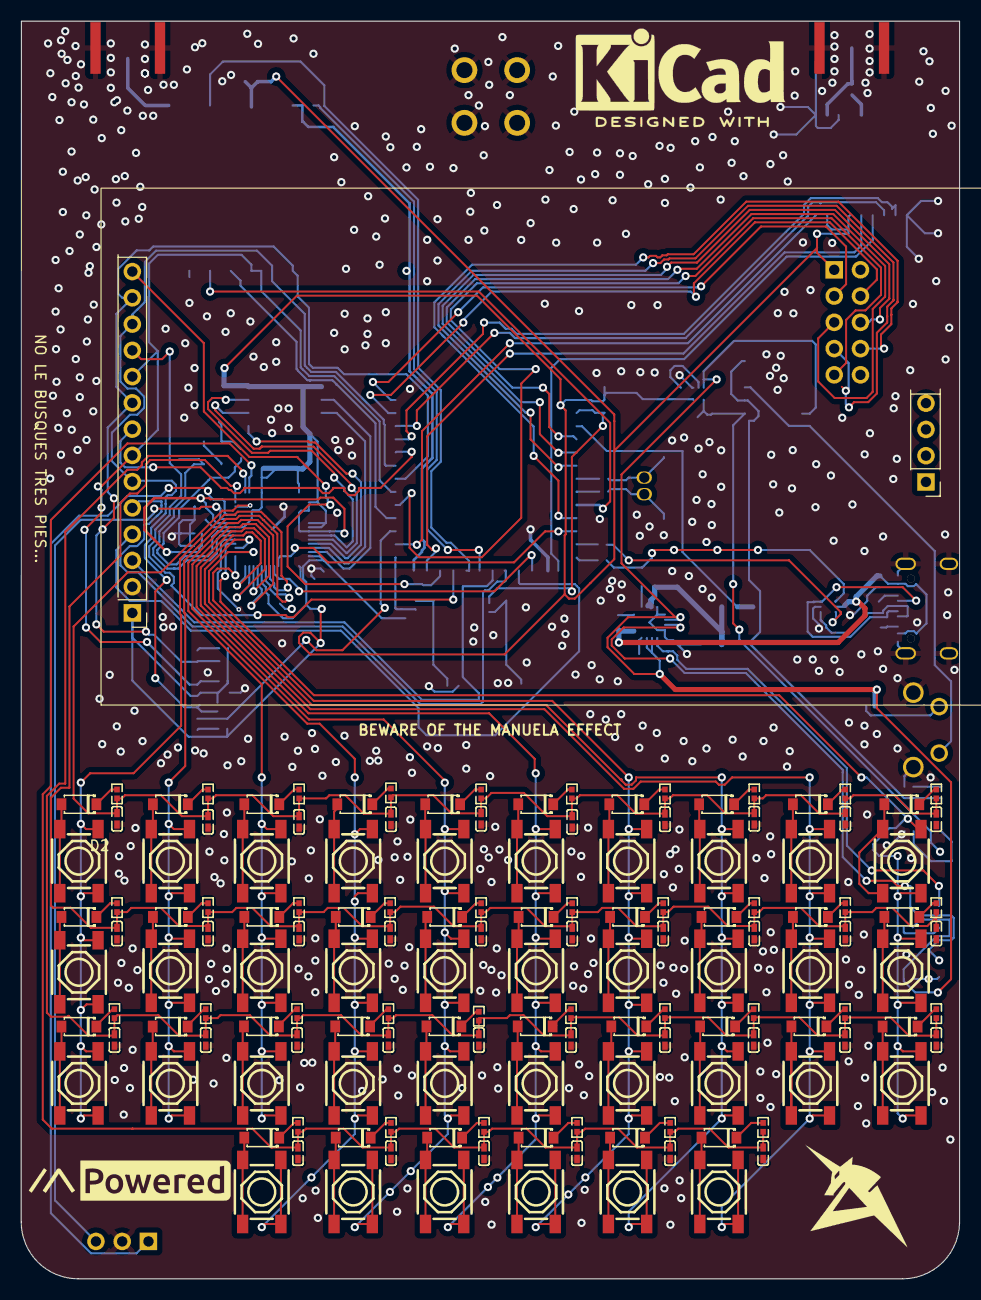
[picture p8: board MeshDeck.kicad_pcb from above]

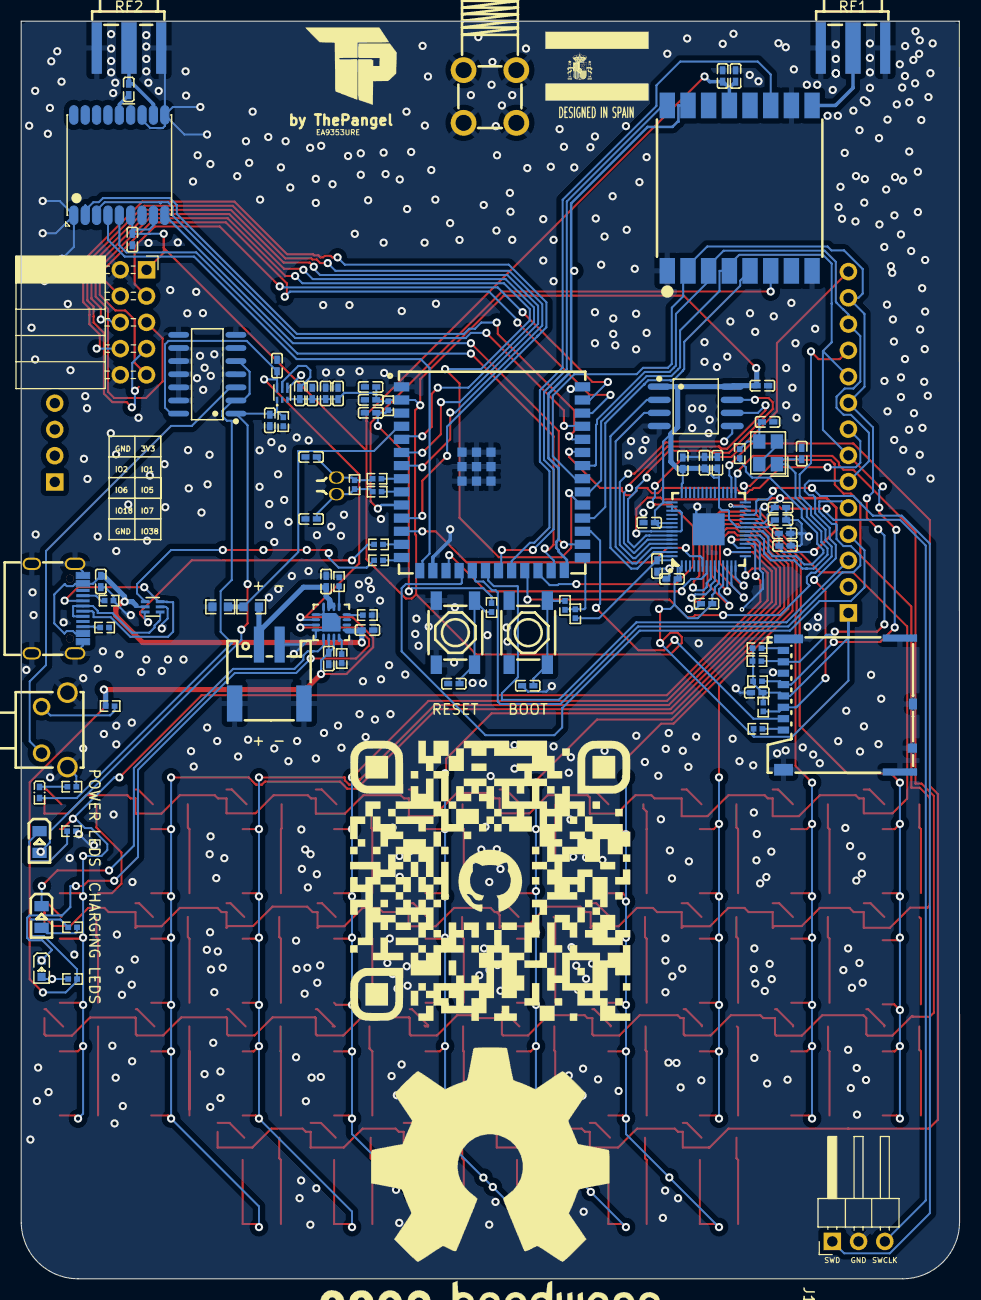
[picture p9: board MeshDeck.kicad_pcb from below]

Board: 4 copper layers, 90.8 x 121.7 mm, 234 parts (89 on the bottom side), 167 nets.

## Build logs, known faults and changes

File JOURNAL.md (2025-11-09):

<!--
  ===================    !!READ THIS NOTICE!!   ====================
  DO NOT edit this file manually. Your changes WILL BE OVERWRITTEN!
  This journal is auto generated and updated by Hack Club Blueprint.
  To edit this file, please edit your journal entries on Blueprint.
  ==================================================================
-->

## 11/3/2025 - Research  

So I want to get into Meshtastic, with a standalone device, but those are expensive, and it be fu to make my own, so inspired by the LILYGO T-Deck I started to research all the components and such, with help from the Meshtastic discord, for now I have the ESP32-S3, a GPS and LoRA module and some components for the battery charging/power circuit.

I still have to add the battery, battery charging IC and all the capacitors resistors and such that work with these components, I have to make my own keyboard and add a screen! (Plus, power, boot and such buttons)


## 11/5/2025 - Research and some circuit building  

So I've been all afternoon reading datasheets and documentation, It's a lot lmao, but I have some circuit build, added usb and powwr supply for the esp, next I need to handle battery charging, step down tp 3.3V, the keyboard etc etc


## 11/9/2025 3 PM - Charging IC circuit   

After like an a couple of hours of reading a datasheet, finding components, etc, I have finished my charging circuit with the BQ24074RGTR as the brains!


## 11/9/2025 4 PM - Added 3.3V step down converter  

To step down the battery voltage to 3.3V i added a TPS6282533DMQ set down converter, to be able to power all my 3.3V components safely, rated for 2A it should be enough.


## 11/9/2025 5 PM - Added crystal oscillator and also tidied up the schematic   

I added a 32.768KHz crystal as an external clocked like stated in the esp datasheet, it is optional but I rather include it because wifi and ble require precise timing, I also made subsheets, also the boot button


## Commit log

2025-11-03 Some initial components
    [MeshDeck.kicad_pcb, MeshDeck.kicad_sch]
2025-11-05 Added ESP-32 and USB stuff
    [MeshDeck.kicad_pcb, MeshDeck.kicad_sch]
2025-11-09 added charging ic circuit
    [MeshDeck.kicad_pcb, MeshDeck.kicad_sch]
2025-11-09 Added 3.3V step down converter
    [MeshDeck.kicad_pcb, MeshDeck.kicad_sch]
2025-11-09 Added oscillator, tidied up with subsheets and added boot btn
    [MeshDeck.kicad_pcb, MeshDeck.kicad_sch, PowerSheet.kicad_sch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]
2025-11-10 set up LoRa module and screen (wip)
    [MeshDeck.kicad_pcb, MeshDeck.kicad_sch]
2025-11-10 Finished screen
    [MeshDeck.kicad_sch]
2025-11-11 Added GPS and sof power button
    [MeshDeck.kicad_pcb, MeshDeck.kicad_sch, PowerSheet.kicad_sch]
2025-11-12 added sd card and started keyboard
    [Keyboard.kicad_sch, MeshDeck.kicad_pcb, MeshDeck.kicad_sch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]
2025-11-13 started pcb plus pin socket for expansion
    [KBMatrix.kicad_sch, Keyboard.kicad_sch, MeshDeck.kicad_pcb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]
2025-11-14 Wired kb matrix
    [MeshDeck.kicad_pcb]
2025-11-14 More routing
    [MeshDeck.kicad_pcb, MeshDeck.kicad_sch]
2025-11-14 Too much routing
    [Keyboard.kicad_sch, MeshDeck.kicad_pcb, MeshDeck.kicad_sch]
2025-11-15 Finished PCB
    [MeshDeck.kicad_pcb]
